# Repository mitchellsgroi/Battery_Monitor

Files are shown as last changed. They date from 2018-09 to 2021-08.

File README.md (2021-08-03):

# Battery_Monitor

Use to monitor Voltage, Current and Amp-Hours of a single 12V sealed lead acid battery.
Also includes temperature monitoring for a fridge freezer.

## About

Despite what 4x4 and caravan accessory companies seem to advertise the state of charge (SoC) of lead acid batteries cannot be determined by measuring voltage alone.

I have created this little Arduino based device to measure the amp-hours that have flowed in and out of the battery to give a more accurate representation of the SoC and hopefully help keep the battery from being overly discharged.

A fairly unique feature of this project is that there is no usage of a shunt to measure current. This is instead achieved by a current sensing coil via hall effect. Therefore installation of the device requires very little modification to existing battery systems.

There is also a demo website included in this repo that gives a basic representation of the monitor in use.

## Notes

- Currently in the process of cleaning everything up after not having being
  touched in over 3 years.

- There are 3 working prototypes in existence that have been running without
  incident now for about 4 or more years including 1 with the current sensor
  mounted in the engine bay.

- I am not going to provide any usage instructions or license at this stage
  until I sort everything out and package it up properly. 

- Contact me if you have any interest in this project and I will help out where I can.

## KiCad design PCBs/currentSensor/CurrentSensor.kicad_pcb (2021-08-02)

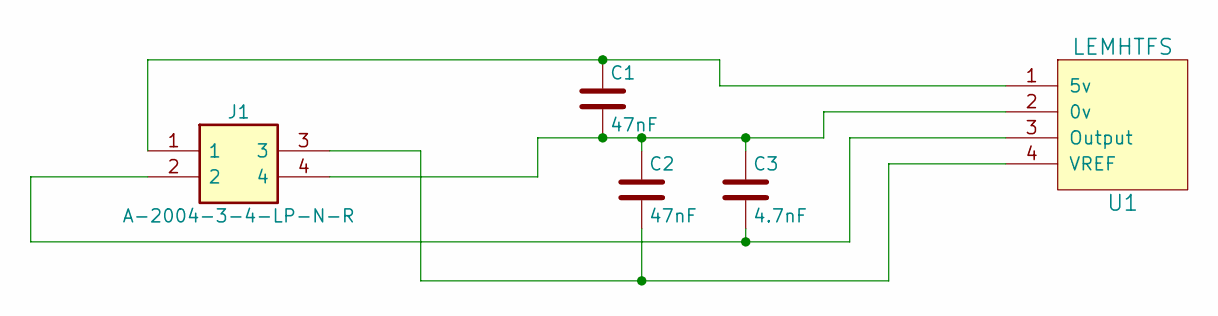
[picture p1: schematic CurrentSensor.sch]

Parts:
C1, C2: 47nF; C_Disc_D4.7mm_W2.5mm_P5.00mm
C3: 4.7nF; C_Disc_D5.0mm_W2.5mm_P2.50mm
J1: A-2004-3-4-LP-N-R; Manufacturer_Part_Number A-2004-3-4-LP-N-R
U1: LEMHTFS; HTFS-Series_LEM-HallEffektCurrentTransducer

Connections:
unnamed: C1.1, J1.1, U1.1 (5v)
unnamed: C1.2, C2.1, C3.1, J1.4, U1.2 (0v)
unnamed: C2.2, J1.3, U1.4 (VREF)
unnamed: C3.2, J1.2, U1.3 (Output)

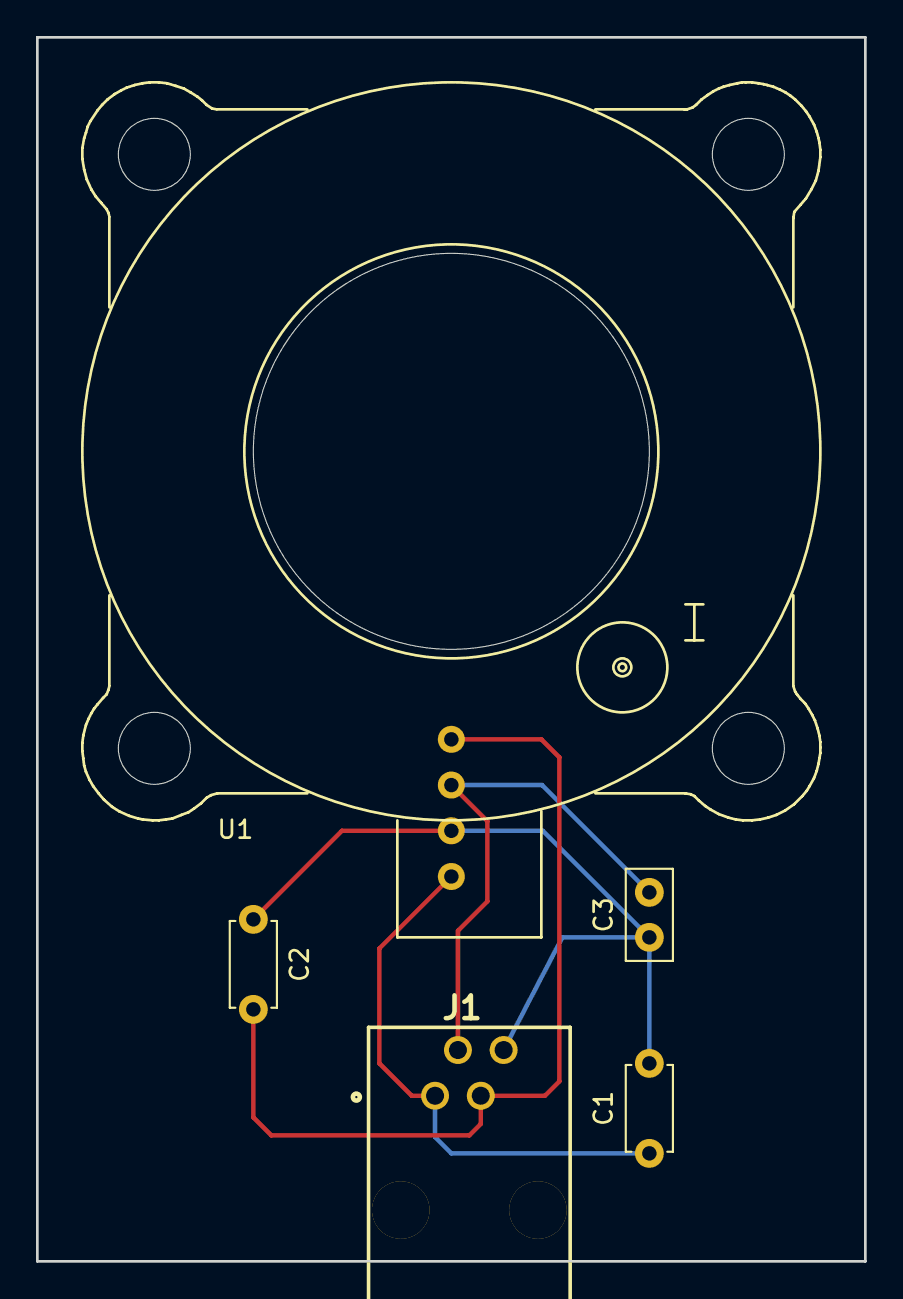
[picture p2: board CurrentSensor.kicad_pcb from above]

Board: 2 copper layers, 46.0 x 68.0 mm, 5 parts (0 on the bottom side), 4 nets.

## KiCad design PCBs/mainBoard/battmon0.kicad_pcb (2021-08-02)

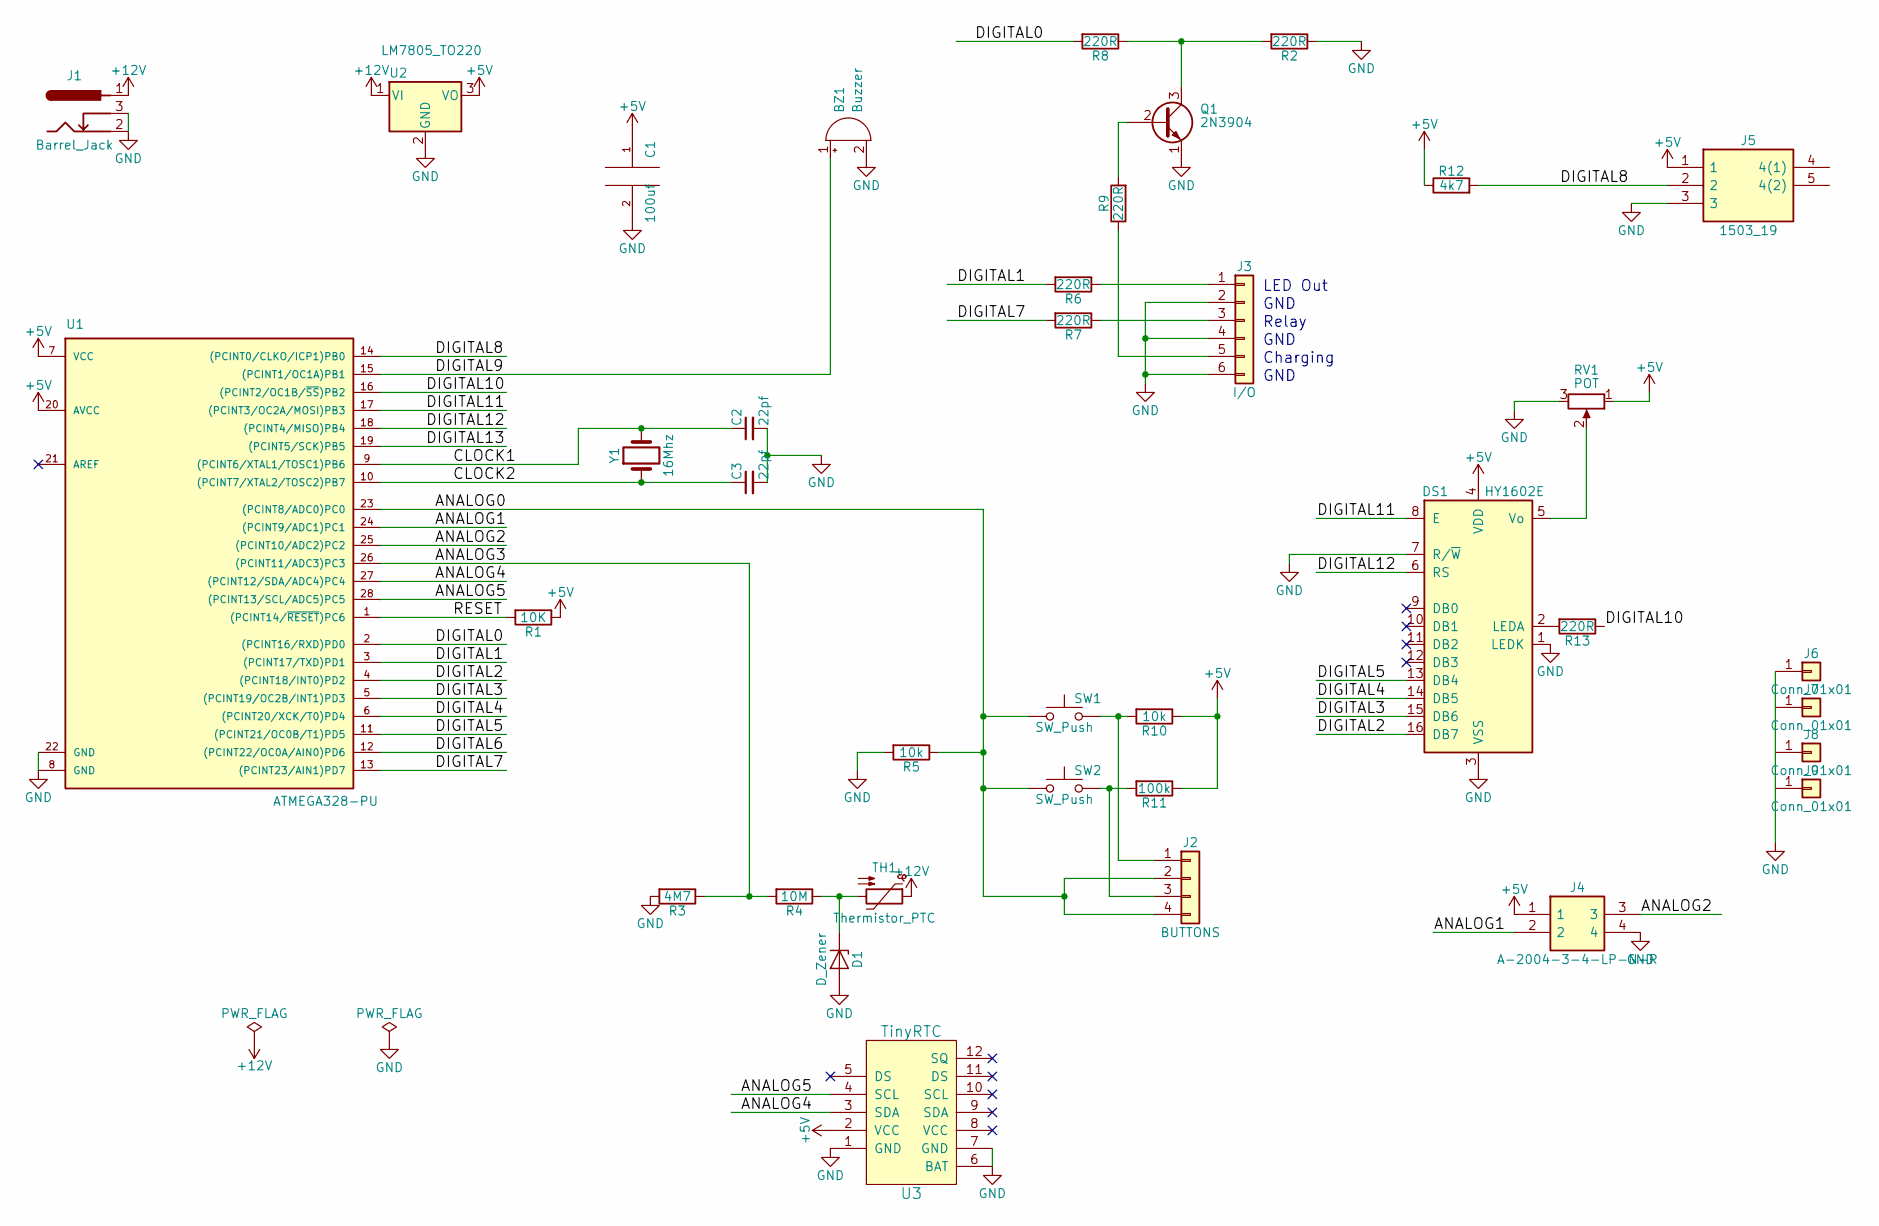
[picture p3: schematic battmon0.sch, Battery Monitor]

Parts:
BZ1: Buzzer; BUZZER
C1: 100uf; CP_Radial_D6.3mm_P2.50mm
C2, C3: 22pf; C_Disc_D3.0mm_W2.0mm_P2.50mm
D1: D_Zener; D_DO-35_SOD27_P7.62mm_Horizontal
DS1: HY1602E; WC1602A
J1: Barrel_Jack; BARREL_JACK
J2: BUTTONS; Molex_KK-6410-04_04x2.54mm_Straight
J3: I/O; Molex_KK-6410-06_06x2.54mm_Straight
J4: A-2004-3-4-LP-N-R; Manufacturer_Part_Number A-2004-3-4-LP-N-R
J5: 1503_19; 1503-19; Manufacturer_Part_Number 1503 19; Farnell Part Number 2677783
J6, J7, J8, J9: Conn_01x01; Mounthole
Q1: 2N3904; TO-92_Molded_Narrow
R1: 10K; R_Axial_DIN0207_L6.3mm_D2.5mm_P10.16mm_Horizontal
R2, R6, R7, R8, R9, R13: 220R; R_Axial_DIN0207_L6.3mm_D2.5mm_P10.16mm_Horizontal
R3: 4M7; R_Axial_DIN0207_L6.3mm_D2.5mm_P10.16mm_Horizontal
R4: 10M; R_Axial_DIN0207_L6.3mm_D2.5mm_P10.16mm_Horizontal
R5, R10: 10k; R_Axial_DIN0207_L6.3mm_D2.5mm_P10.16mm_Horizontal
R11: 100k; R_Axial_DIN0207_L6.3mm_D2.5mm_P10.16mm_Horizontal
R12: 4k7; R_Axial_DIN0207_L6.3mm_D2.5mm_P10.16mm_Horizontal
RV1: POT; Potentiometer_Triwood_RM-065
SW1, SW2: SW_Push; SW_PUSH_6mm_h9.5mm
TH1: Thermistor_PTC; R_Axial_DIN0204_L3.6mm_D1.6mm_P5.08mm_Vertical
U1: ATMEGA328-PU; DIP-28_W7.62mm
U2: LM7805_TO220; TO-220-3_Vertical
U3: TinyRTC
Y1: 16Mhz; Crystal_HC49-U_Vertical

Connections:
+5V: C1.1, DS1.4 (VDD), J4.1, J5.1, R1.1, R10.1, R11.1, R12.1, RV1.1, U1.7 (VCC), U1.20 (AVCC), U2.3 (VO), U3.2 (VCC)
+12V: J1.1, TH1.1, U2.1 (VI)
/ANALOG0: J2.2, J2.4, R5.1, SW1.1, SW2.1, U1.23 ((PCINT8/ADC0)PC0)
/ANALOG1: J4.2, U1.24 ((PCINT9/ADC1)PC1)
/ANALOG2: J4.3, U1.25 ((PCINT10/ADC2)PC2)
/ANALOG3: R3.1, R4.2, U1.26 ((PCINT11/ADC3)PC3)
/ANALOG4: U1.27 ((PCINT12/SDA/ADC4)PC4), U3.3 (SDA)
/ANALOG5: U1.28 ((PCINT13/SCL/ADC5)PC5), U3.4 (SCL)
/CLOCK1: C2.1, U1.9 ((PCINT6/XTAL1/TOSC1)PB6), Y1.2
/CLOCK2: C3.1, U1.10 ((PCINT7/XTAL2/TOSC2)PB7), Y1.1
/DIGITAL0: R8.2, U1.2 ((PCINT16/RXD)PD0)
/DIGITAL1: R6.2, U1.3 ((PCINT17/TXD)PD1)
/DIGITAL2: DS1.16 (DB7), U1.4 ((PCINT18/INT0)PD2)
/DIGITAL3: DS1.15 (DB6), U1.5 ((PCINT19/OC2B/INT1)PD3)
/DIGITAL4: DS1.14 (DB5), U1.6 ((PCINT20/XCK/T0)PD4)
/DIGITAL5: DS1.13 (DB4), U1.11 ((PCINT21/OC0B/T1)PD5)
/DIGITAL6: U1.12 ((PCINT22/OC0A/AIN0)PD6)
/DIGITAL7: R7.2, U1.13 ((PCINT23/AIN1)PD7)
/DIGITAL8: J5.2, R12.2, U1.14 ((PCINT0/CLKO/ICP1)PB0)
/DIGITAL9: BZ1.1 (-), U1.15 ((PCINT1/OC1A)PB1)
/DIGITAL10: R13.1, U1.16 ((PCINT2/OC1B/~SS~)PB2)
/DIGITAL11: DS1.8 (E), U1.17 ((PCINT3/OC2A/MOSI)PB3)
/DIGITAL12: DS1.6 (RS), U1.18 ((PCINT4/MISO)PB4)
/DIGITAL13: U1.19 ((PCINT5/SCK)PB5)
/RESET: R1.2, U1.1 ((PCINT14/~RESET~)PC6)
GND: BZ1.2 (+), C1.2, C2.2, C3.2, D1.2 (A), DS1.1 (LEDK), DS1.3 (VSS), DS1.7 (R/~W), J1.2, J1.3, J3.2, J3.4, J3.6, J4.4, J5.3, J6.1, Q1.1 (E), R2.1, R3.2, R5.2, RV1.3, U1.8 (GND), U1.22 (GND), U2.2 (GND), U3.1 (GND), U3.6 (BAT), U3.7 (GND)
unnamed: D1.1 (K), R4.1, TH1.2
unnamed: DS1.2 (LEDA), R13.2
unnamed: DS1.5 (Vo), RV1.2
unnamed: J2.1, R10.2, SW1.2
unnamed: J2.3, R11.2, SW2.2
unnamed: J3.1, R6.1
unnamed: J3.3, R7.1
unnamed: J3.5, R9.1
unnamed: Q1.2 (B), R9.2
unnamed: Q1.3 (C), R2.2, R8.1

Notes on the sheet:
LED Out
Relay
GND
Charging

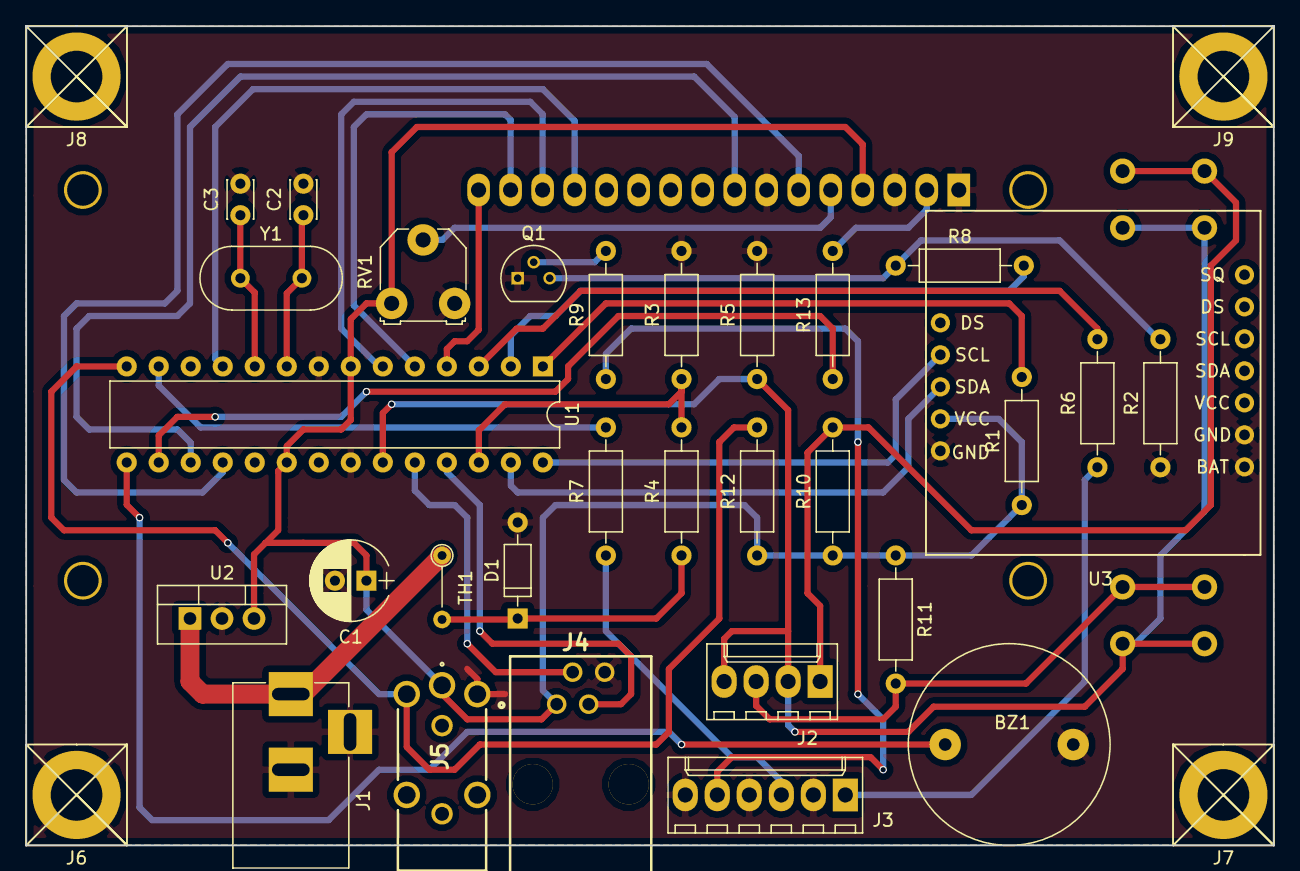
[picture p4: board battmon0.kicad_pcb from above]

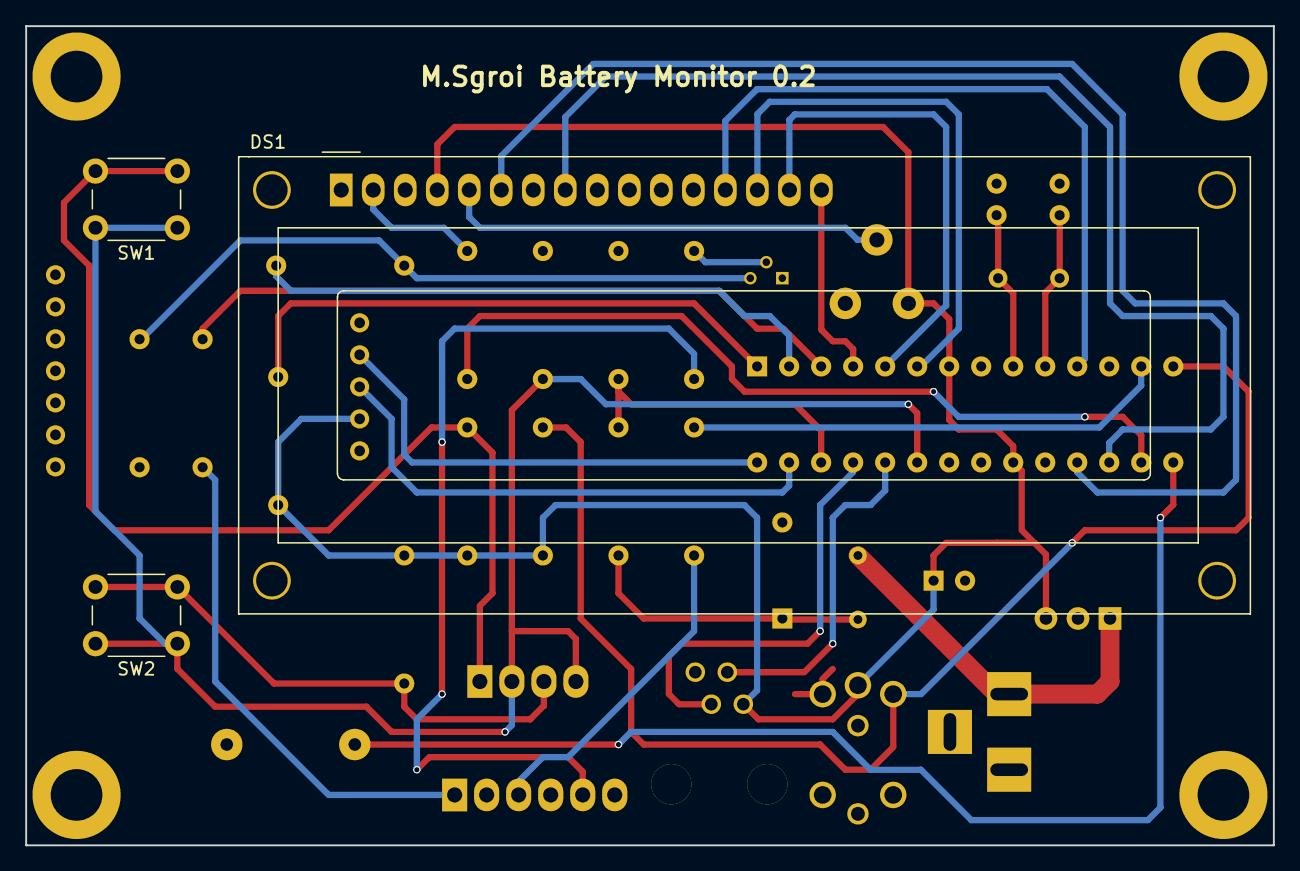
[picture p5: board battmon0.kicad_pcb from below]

Board: 2 copper layers, 99.0 x 65.0 mm, 37 parts (3 on the bottom side), 34 nets.

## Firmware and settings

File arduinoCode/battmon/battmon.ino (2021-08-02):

/*
## TODO
    - DONE-- Change the 15 second interval thing to variable --DONE
    - DONE-- EEPROM Stuff, save the settings, read them and set defaults if no good --DONE
    - Temperature probes, can I have two?
    - DONE-- Fix Enter Setup --DONE
    - DONE-- Make the setup screens actually work --DONE
    - DONE-- Make the alarms actually work --DONE
    - DONE-- Get current readings --DONE
    - DONE-- Stopwatch the AH reading for accuracy --DONE
    - DONE-- truncate the AH rather than round --DONE
    - DONE-- fall back to millis if rtc is broken--DONE
    - DONE-- add rtc status screen in setup --DONE
    - DONE-- Fix display bugs in setup screens -- DONE
    - DONE--Put all the settings into an array of bytes --DONE
    - DONE-- Handle wrong settings --DONE
    - Comment everything
    - DONE-- write float detection --DONE
    - DONE-- Write charge detection current & charge signal --DONE
    - Done-- Write battery capacity tester --Done
    - Done-- Make work on old PCB --DONE
    - Make work on new PCB
    - DONE-- Address amp hour reset bug in capacity tester --DONE
    - DONE-- Change float so only triggered after set time (15min) --DONE
    - DONE-- adjust alarm screens for consistancy. --DONE
    - add amp hour alarm
    - add option to trigger relay on alarm
    - Rearrange code/functions so everything is in an order that makes sense
    - DONE-- Rewrite setup screens to account for extra temp probes --DONE

## BUGS
    - Erratic current readings in test vehicle when running fridge. Switches between positive and negative triggering the charge LED
        - Added smoothing tp each reading before combining them with the LEM current formula. Initial testing shows stable current.
    
    - Float detection will reset amp hours as voltage settles when charger is turned off mid charge.
        - Added a time delay of approx 10min. Monitor must see float conditions for this 10min before resetting amp hours.

    - Backlight doesn't light up while initialising.
        - Initialise pins before startup tests.

    - 2nd Run PCB has different LCD pinout than expected.
        - Use wire instead of terminal strip

    - Amp hours don't reset correctly, flashes 0 then returns to previous number
        - set ampHoourFloat to zero also and retest

    - Float detection needs some fine tuning, rarely detects float
    

*/
// LIBRARIES
#include <Wire.h>
#include "RTClib.h"
#include <LiquidCrystal.h>
#include <EEPROM.h>
#include <OneWire.h>
#include <DallasTemperature.h>

// DEFINITIONS
//#define PROTO
#define PCBONE
//#define PCBTWO

//#define DEBUG
//#define TESTING

#define BUTTON_NONE     0
#define BUTTON_ENTER    1
#define BUTTON_SELECT   2

#define NORMAL 5
#define SETUP 6

#define SETTING_SIZE 30

#define VHAT 0  // Volt High Alarm Tens
#define VHAO 1  // Volt High Alarm Ones 
#define VHAP 2  // Volt High Alarm Point
#define VLAT 3  // Volt Low Alarm Tens
#define VLAO 4
#define VLAP 5

#define THAS 6
#define THAT 7
#define THAO 8
#define THAP 9

#define TLAS 10
#define TLAT 11
#define TLAO 12
#define TLAP 13

#define THAST 14
#define THATT 15
#define THAOT 16
#define THAPT 17

#define TLAST 18
#define TLATT 19
#define TLAOT 20
#define TLAPT 21

#define VA 22
#define TA 23
#define TAT 24

#define WA 25   // Which Alarm

 



// INITIALISE

#ifdef PROTO
    #define ONE_WIRE_BUS 11

    
    
    LiquidCrystal lcd(8,9,4,5,6,7);
    const int chargePin = 2;
    const int backlightPin = 3;
    const int buttonPin = A0;
    const int voltPin = A3;
    const int ledPin = 12;
    const int buzzerPin = 13;
    const int relayPin = 10;

    const int currentVrefPin = A1;
    const int currentVoutPin = A2;


    // VOLTAGE
    float topVolts = 5;
    float kVolts = 1.0;

    // CURRENT
    float kCurrent = 0;

    // BUTTON LEVELS
    int selectVolts = 740;
    int enterVolts = 140;
    
    // FLOAT DETECTION
    float maxVoltage = 0;
    float floatVoltage = 3.0;
    float chargeVoltage = 4.2;
    bool floating = false;
    int floatSeconds = 0;   
    int floatSecondsMax = 600;    

#endif

#ifdef PCBONE // Original PCB
    
    #define ONE_WIRE_BUS 8
    
    LiquidCrystal lcd(12,11,5,4,3,2);

    const int chargePin = 0;
    const int ledPin = 1;
    const int buzzerPin = 9;
    const int backlightPin = 10;
    const int relayPin = 13;
     
    const int buttonPin = A0;
    const int currentVoutPin = A1;
    const int currentVrefPin = A2;
    const int voltPin = A3;

    // VOLTAGE
    float topVolts = 28.5;

    // My car
    float kVolts = 0.97;

    // CURRENT
    float kCurrent = 0.0;

    // BUTTON VOLTAGES
    int selectVolts = 790;
    int enterVolts = 260;

    // FLOAT DETECTION
    float maxVoltage = 0;
    float floatVoltage = 13.2;
    float chargeVoltage = 13.9;
    bool floating = false;
    int floatSeconds = 0;   
    int floatSecondsMax = 600;
     
#endif

#ifdef PCBTWO
    #define ONE_WIRE_BUS 8
    
    LiquidCrystal lcd(12,11,5,4,3,2);

    const int chargePin = 0;
    const int ledPin = 1;
    const int buzzerPin = 9;
    const int backlightPin = 10;
    const int relayPin = 7;
     
    const int buttonPin = A0;
    const int currentVoutPin = A1;
    const int currentVrefPin = A2;
    const int voltPin = A3;

    // VOLTAGE
    float topVolts = 28.5;
    
    //Jayson's Car
    float kVolts = 0.985;
    
    // CURRENT
    float kCurrent = 0.0;

    // BUTTON VOLTAGES
    int selectVolts = 509;
    int enterVolts = 90;

    // FLOAT DETECTION
    float maxVoltage = 0;
    float floatVoltage = 13.4;
    float chargeVoltage = 14.1;
    bool floating = false;
    int floatSeconds = 0;   
    int floatSecondsMax = 600;
    
     
#endif
    

RTC_DS1307 RTC;

OneWire oneWire(ONE_WIRE_BUS);
DallasTemperature sensors(&oneWire);

// VARIABLES

// RTC and Timing
int currentSecond = 0;  // reading the seconds from the RTC
int wasSecond = 0;      // to compare seconds to the last loop
byte secondPassed = false;
byte fifteenSecond = false;
byte fifteenSecondCount = 0;
byte fifteenSecondMax = 15;

byte tempAdvance = false;
byte tempAdvanceCount = 0;
byte tempAdvanceMax = 5;

unsigned long currentMillis = 0;  // millis for each loop for delays
unsigned long refreshMillis = 0;
const int refreshDelay = 1000;
byte refresh = false;

const int numReadings = 50;

// ALARMS
String tempHighString = ("Maximum Temp");
String tempLowString = ("Minimum Temp");
String voltHighString = ("Maximum Volts");
String voltLowString = ("Minimum Volts");
String plus = "+";
String neg = "-";

String no = "No";
String yes = "Yes";

byte settings[SETTING_SIZE];

byte tempAlarm[2];
float tempLowAlarm[2];
float tempHighAlarm[2];
byte tempAlarming[2];

byte voltAlarm = 0;
float voltLowAlarm = 0;
float voltHighAlarm = 0;
byte voltAlarming = false;

int alarmCount = 0;
int alarmMax = 2000;

bool ledOn = false;

// current
int vRefRaw = 0;
int totalVref = 0;
int arrayVref[numReadings];
int iVref = 0;
float vRefAverage = 0;

int vOutRaw = 0;
int totalVout = 0;
int arrayVout[numReadings];
int iVout = 0;
float vOutAverage = 0;
//float vRef = 0;
//float vOut = 0;
float thisCurrent = 0;
float totalCurrent = 0;
float arrayCurrent[numReadings];
int iCurrent = 0;

float current = 0;       // final current to be displayed

// voltage


float voltage = 12.5;     // final voltage to be displayed
int rawVolts = 0;
int arrayVolts[numReadings];
float totalVolts = 0;
int iVolts = 0;
byte voltSetCount = 0;

// CHARGING

int chargeHigh = LOW;
bool isCharging = false;


// Battery Testing
byte batteryTest = 0;
byte startTesting = 0;
byte isTesting = 0;
byte doneTesting = true;
float testResult = 0;
bool relayOn = false;


// amp hours
int ampHours = 0;     // total amp hours
float ampHourFloat = 0;
byte ampHourReset = 0;

// temperature
float tempReadings[2];
byte tempIndex = 0;
int numTempSensors = 0;


// buttons
unsigned long buttonMillis = 0;
const int buttonDelay = 50;
const int buttonHyst = 10; // How many volts above or below the ones set above
int rawButton = 0;
byte whichButton = 0;
byte buttonAction = false;
byte buttonPressed = 0;
byte buttonWas = 0;

int screenReturn = 0;
int screenMax = 3000;

byte *selectAddress;
byte *enterAddress;

byte selectModulo = 0;
byte enterModulo = 0;

// CURSOR AND ALARM FLASHING
byte flashState = true;
unsigned long lastFlashMillis = 0;
const int flashDelay = 250;


// settings
byte selectCount = 0;
byte backlightLevel = 0;
byte setupCount = 0;
byte tempSetCount = 0;
byte numScreens = 5;

byte enterSetup = false;
byte exitSetup = 0;

// AH SYMBOL
byte ahSymbol[8] = {
  B01000,
  B10100,
  B11100,
  B10100,
  B00000,
  B00101,
  B00111,
  B00101,
};

String tempAlarmHeader = "Temp Range";


void setup() {
    // NEW BEGININGS
     Wire.begin();
    lcd.createChar(2, ahSymbol);
    lcd.begin(16,2);
    
   
    RTC.begin();
    // sensors.begin();  // Moved to function

    // PIN THE TAIL ON THE DONKY
    pinMode(backlightPin, OUTPUT);
    pinMode(ledPin, OUTPUT);
    pinMode(buzzerPin, OUTPUT);
    pinMode(relayPin, OUTPUT);   
    pinMode(buttonPin, INPUT);
    #ifdef PCBONE
        pinMode(buttonPin, INPUT_PULLUP);
    #endif
    pinMode(voltPin, INPUT);
    pinMode(currentVrefPin, INPUT);
    pinMode(currentVoutPin, INPUT);
    

    digitalWrite(backlightPin, HIGH);
    digitalWrite(ledPin, LOW);
    digitalWrite(buzzerPin, LOW);
    digitalWrite(relayPin, HIGH);

    if (!RTC.isrunning()){
        lcd.clear();
        lcd.print(F("RTC Resetting"));
        delay(200);
        RTC.adjust(DateTime(__DATE__, __TIME__)); 
    }

    if (!RTC.isrunning()){
        lcd.clear();
        lcd.print(F("RTC ERROR"));
        delay(2000);
    }

    // PRINT TO LCD AS FAUX SPLASH SCREEN
    lcd.clear();
    lcd.print(F("  The Battery   "));
    lcd.setCursor(0, 1);
    lcd.print(F("    Monitor     "));
    delay(300);



    // CLEAR AVERAGING ARRAYS
    for (int i = 0; i < numReadings; i++) {
        arrayVolts[i] = 0;
        arrayCurrent[i] = 0;
        arrayVref[i] = 0;
        arrayVout[i] = 0;
    }

//    // Read the temps sensor on startup
//    sensors.requestTemperatures();
//    // ping the sensor(s) for the temp reading
//    temp = sensors.getTempCByIndex(0);

    

    // read persistant values from the EEPROM
    settingsRead();

    // set up the alarm values
    convertAlarms();

    setupTempSensors();
    
    lcd.clear();
    
}

void setupTempSensors() {

    // check the number of temp sensors connected
    // make a correctly sized array to store the values
    // read all the temps and save them to the array (for loop)
    // either return the array or make a global variable.
    
    sensors.begin();
    delay(10);
    numTempSensors = sensors.getDeviceCount();

    if (numTempSensors > 2) {
        numTempSensors = 2;
    }

    lcd.clear();
    lcd.print(numTempSensors);
    lcd.print(F(" Temp Probe(s)"));
    delay(500);

    sensors.requestTemperatures();

    for (int i = 0; i < numTempSensors; i++) {
        tempReadings[i] = sensors.getTempCByIndex(i);
    }
}

void loop() {
    // Do all the millis related functions
    checkMillis();
    // Do all the second related functions
    checkSecond();
    // Check the voltage of the battery
    batteryVoltage();
    // Check the current in or out of the battery
    batteryCurrent();
    // Check if the battery is floating
    floatDetect();
    // Check if the battery is charging
    charging();
    // Check the temperature
    temperature();     
    // Count the Amp Hours
    countAmpHours();
    // Trigger any alarms
    triggerTempAlarm(0, TA);
    if (numTempSensors > 1) {
        triggerTempAlarm(1, TAT);
    }
    else {
        tempAlarming[1] = false;
    }
    triggerVoltAlarm();
    // Set off buzzer or LED
    soundAlarm();
    // Check if a button has been presseds
    buttons();
    // Print info the the LCD
    displayScreen();
    // Return to home screen if no activity
    returnHome();   
}

byte checkButton(){

    rawButton = analogRead(buttonPin);
    
    if (rawButton > (selectVolts - buttonHyst) && rawButton < (selectVolts + buttonHyst)) {
        buttonPressed = BUTTON_SELECT;
    }
    else if (rawButton > (enterVolts - buttonHyst) && rawButton < (enterVolts + buttonHyst)) {
        buttonPressed = BUTTON_ENTER;
    }
    else {
        buttonPressed = BUTTON_NONE;
    }

    if (buttonWas == BUTTON_NONE && buttonPressed != BUTTON_NONE) {
        buttonAction = true;
    }

    buttonWas = buttonPressed;

    return buttonPressed;
}

void setBack() {
    // Sets the level of the LCD backlight
    switch (backlightLevel) {
        case 0:
            digitalWrite(backlightPin, HIGH);
        break;
        case 1:
            analogWrite(backlightPin, 127);
        break;
        case 2:
            digitalWrite(backlightPin, LOW);
        break;
    }
}
void checkMillis() {
    // capture millis at the start of the loop
    currentMillis = millis();
    
    if ((currentMillis - refreshMillis) > refreshDelay) {
        refresh = true;
        refreshMillis = currentMillis;
    }

    else {
        refresh = false;
    }
    if ((currentMillis - lastFlashMillis) > flashDelay) {
        flashState = !flashState;
        lastFlashMillis = currentMillis;
    }
}

void checkSecond() {
    if (RTC.isrunning()){

        DateTime now = RTC.now();
        currentSecond = now.second();
    
        if (currentSecond != wasSecond) {
            secondPassed = true;
        }
        else {
            secondPassed = false;
        }
    
        // change the magic 15 here to a variable that can be changed
        if (((currentSecond % fifteenSecondMax) == 0) && secondPassed) {
            fifteenSecond = true;
        }
        else {
            fifteenSecond = false;
        }

        if (((currentSecond % tempAdvanceMax) == 0) && secondPassed) {
            tempAdvance = true;
        }
        else {
            tempAdvance = false;
        }
        
        wasSecond = currentSecond;
    }
    else {
         if (refresh) {
            secondPassed = true;
            if (fifteenSecondCount >= fifteenSecondMax) {
                fifteenSecond = true;
                fifteenSecondCount = 0;
            }
            fifteenSecondCount++;

            if (tempAdvanceCount >= tempAdvanceMax) {
                tempAdvance = true;
                tempAdvanceCount = 0;
            }
            tempAdvanceCount++;
         }
         else {
            secondPassed = false;
            fifteenSecond = false;
            tempAdvance = false;
         }
    }
}

void batteryVoltage() {
    // Take the analog input
    rawVolts = analogRead(voltPin);
    // Take the old value from the total
    totalVolts -= arrayVolts[iVolts];
    // Put the new value in the array
    arrayVolts[iVolts] = rawVolts;
    // Add the new value to the array
    totalVolts += arrayVolts[iVolts];
    // increment the array index
    iVolts++;
    // reset the index at the end of the array
    if (iVolts >= numReadings) {
        iVolts = 0;
    }
    delay[1];

    // calculate average voltage
    voltage = ((totalVolts / numReadings) * (topVolts / 1023.0)) * kVolts;    
}



void batteryCurrent() {
    
    vRefRaw = analogRead(currentVrefPin);
    vOutRaw = analogRead(currentVoutPin);

    // take the old value from the total
    totalVref -= arrayVref[iVref];
    // Insert the new value
    arrayVref[iVref] = vRefRaw;
    // Add this new value to the total
    totalVref += arrayVref[iVref];
    // Go to next index
    iVref++;
    // Reset index if at the end of array
    if (iVref >= numReadings) {
        iVref = 0;
    }
    delay[1];

    vRefAverage = totalVref / numReadings;


        // take the old value from the total
    totalVout -= arrayVout[iVout];
    // Insert the new value
    arrayVout[iVout] = vOutRaw;
    // Add this new value to the total
    totalVout += arrayVout[iVout];
    // Go to next index
    iVout++;
    // Reset index if at the end of array
    if (iVout >= numReadings) {
        iVout = 0;
    }
    delay[1];

    vOutAverage = totalVout / numReadings;
    

    thisCurrent = 160 * (vOutAverage - vRefAverage);

    // take the old value from the total
    totalCurrent -= arrayCurrent[iCurrent];
    // Insert the new value
    arrayCurrent[iCurrent] = thisCurrent;
    // Add this new value to the total
    totalCurrent += arrayCurrent[iCurrent];
    // Go to next index
    iCurrent++;
    // Reset index if at the end of array
    if (iCurrent >= numReadings) {
        iCurrent = 0;
    }
    delay[1];

    // calculate the average
    current = ((totalCurrent / numReadings) * (5.0 / 1023.0)) + kCurrent;

    if (current < 0.4 && current > -0.4) {
        current = 0;
    }
    
    
}

void countAmpHours() {
    if (secondPassed) {
        ampHourFloat += current / 3600;

        if (ampHourFloat < 0) {
            ampHourFloat = 0;
        }

    ampHours = ampHourFloat;
    }
}

void temperature() {
    // TEMPERATURE
    if (fifteenSecond && !selectCount && !batteryTest) {
        // request readings from all temp sensors
        sensors.requestTemperatures();
        // save the readings to the array
        for (int i = 0; i < numTempSensors; i++) {
            tempReadings[i] = sensors.getTempCByIndex(i);
        }
    }    
}

void triggerTempAlarm(byte i, byte settingIndex) {
    switch(settings[settingIndex]) {
        case 0:
            tempAlarming[i] = false;
        break;
        case 1:
            if (tempReadings[i] >= tempHighAlarm[i] || tempReadings[i] <= tempLowAlarm[i]) {
                tempAlarming[i] = true;
                alarmCount = alarmMax;
            }
            else {
                tempAlarming[i] = false;
            }
        break;
        case 2:
            if (tempReadings[i] >= tempHighAlarm[i]) {
                tempAlarming[i] = true;
                alarmCount = alarmMax;
            }
            else {
                tempAlarming[i] = false;
            }
        break;    
        case 3:
            if (tempReadings[i] <= tempLowAlarm[i]) {
                tempAlarming[i] = true;
                alarmCount = alarmMax;
            }
            else {
                tempAlarming[i] = false;
            }
        break;
    }


}

void triggerVoltAlarm() {
    switch(settings[VA]) {
        case 0:
            voltAlarming = false;
        break;
        case 1:
            if (voltage >= voltHighAlarm || voltage <= voltLowAlarm) {
                voltAlarming = true;
                alarmCount = alarmMax;
            }
            else {
                voltAlarming = false;
            }
        break;
        case 2:
            if (voltage >= voltHighAlarm) {
                voltAlarming = true;
                alarmCount = alarmMax;    
            }
            else {
                voltAlarming = false;
            }
        break;
        case 3:
            if (voltage <= voltLowAlarm) {
                voltAlarming = true;
                alarmCount = alarmMax;
            }
            else {
                voltAlarming = false;
            }
        break;
    }
}


void soundAlarm() {
    if (voltAlarming || tempAlarming[0] || tempAlarming[1] || alarmCount) {
        switch (settings[WA]) {
            case 0:
             setLed(0);
             digitalWrite(buzzerPin, LOW);
            break;
            case 1:
                flashLed();
                flashBuzzer();
            break;
            case 2:
                flashLed();
                digitalWrite(buzzerPin, LOW);
            break;
            case 3:
                flashBuzzer();
                setLed(0);
            break;
        }
    }
    else {
        if (isCharging) {
            setLed(1);
        }
        else {
            setLed(0);
        }
        digitalWrite(buzzerPin, LOW);
    }

    if ((!voltAlarming || !tempAlarming[0] || !tempAlarming[1]) && alarmCount > 0) {
        alarmCount-- ;
    }
    
}

void buttons() {
    // Check the button press wasn't a bounce
    if ((currentMillis - buttonMillis) > buttonDelay) {
        // check which button it was
        whichButton = checkButton();
        // reset the debounce timer
        buttonMillis = currentMillis;
        // check if the button pressed should trigger an action
        if (buttonAction == true) {
            // reset the activity timer
            screenReturn = 0;
            // do the action that is required
            buttonIncrement();
            // reset the action trigger
            buttonAction = false;
        }
    }
}

void returnHome() {
    // If not on the home screen    
    if (selectCount != 0) {
        // Increment the count
        screenReturn++;
        // If count has reached the max value
        if (screenReturn >= screenMax) {
            // Clear the LCD
            lcd.clear();
            // Return to the home screen
            selectCount = 0;
            // Reset the count
            screenReturn = 0;
        }
    }
}
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

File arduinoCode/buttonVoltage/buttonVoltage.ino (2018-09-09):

/*
  LiquidCrystal Library - display() and noDisplay()

 Demonstrates the use a 16x2 LCD display.  The LiquidCrystal
 library works with all LCD displays that are compatible with the
 Hitachi HD44780 driver. There are many of them out there, and you
 can usually tell them by the 16-pin interface.

 This sketch prints "Hello World!" to the LCD and uses the
 display() and noDisplay() functions to turn on and off
 the display.

 The circuit:
 * LCD RS pin to digital pin 12
 * LCD Enable pin to digital pin 11
 * LCD D4 pin to digital pin 5
 * LCD D5 pin to digital pin 4
 * LCD D6 pin to digital pin 3
 * LCD D7 pin to digital pin 2
 * LCD R/W pin to ground
 * 10K resistor:
 * ends to +5V and ground
 * wiper to LCD VO pin (pin 3)

 Library originally added 18 Apr 2008
 by David A. Mellis
 library modified 5 Jul 2009
 by Limor Fried (http://www.ladyada.net)
 example added 9 Jul 2009
 by Tom Igoe
 modified 22 Nov 2010
 by Tom Igoe
 modified 7 Nov 2016
 by Arturo Guadalupi

 This example code is in the public domain.

 http://www.arduino.cc/en/Tutorial/LiquidCrystalDisplay

*/

// include the library code:
#include <LiquidCrystal.h>

// initialize the library by associating any needed LCD interface pin
// with the arduino pin number it is connected to
const int rs = 12, en = 11, d4 = 5, d5 = 4, d6 = 3, d7 = 2;
LiquidCrystal lcd(rs, en, d4, d5, d6, d7);

int backlightPin = 10;
int buttonPin = A0;

int voltage = 0;

void setup() {
  // set up the LCD's number of columns and rows:
  pinMode(backlightPin, OUTPUT);
  digitalWrite(backlightPin, HIGH);

  pinMode(buttonPin, INPUT);
  
  lcd.begin(16, 2);
  
  // Print a message to the LCD.
  
}

void loop() {
    lcd.clear();
    lcd.setCursor(0, 0);
    lcd.print("Button Voltage");
    voltage = analogRead(buttonPin);
    lcd.setCursor(0, 1);
    lcd.print(voltage);
}

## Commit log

2018-03-24 Further setup of repo
    Added TODOs and BUGS to readme.
    Fixed folder structure to suit arduino ide
    [battmon.ino]
2018-05-13 add RTC test
    Added a sketch for testing the RTC.
    Adds 1 every second and prints the number to the LCD. Use stopwatch to compare accuracy.
2018-05-14 Make buttons work
    Delete all old code and start from scratch. Make the buttons count when pressed
2018-05-14 add screen placeholders
    Adjusted buttons, added screen placeholders, implemented RTC second counting
2018-05-15 add volt reading and smoothing, add amphour symbol
2018-05-16 Set up alarm screens
    Made the alarm screens work. added amp hour reset functionality. Added return to home screen automatically
    [battmon.ino]
2018-05-17 Fix access to setup menu
    Can now enter and exit the settings menu
    [battmon.ino]
2018-05-19 Develop setting screens
    Addes flash function to create faux cursor. Solved some issues with the RTC.
    [battmon.ino]
2018-05-19 Nut out pointer stuff for buttons
2018-05-19 develop settings screens
    Make the temperature alarm setting screens work
2018-05-21 Volt and Temp alarms
    Made the alarms trigger at the set values
2018-05-23 Make thermometer and current reading work
2018-05-23 Capacity Tester
2018-05-26 work towards full PCB compatibility
2018-05-27 Revert "work towards full PCB compatibility"
    This reverts commit 5e2b64584d89cdf549f13917bd7779cb2c238dab.
    [battmon.ino]
2018-05-27 Revert "scrap softwire"
    This reverts commit 2c057f420a9aba92f44af993ab14fa2e42b0b61f.
    [battmon.ino, buttonVoltage.ino]
2018-05-28 add timer to float detect
2018-05-31 Stabilise Current Readings
    Current readings were erratic during testing. Added a layer of smoothing to each analog pin before combining and smoothing again.
    [battmon.ino]
2018-05-31 Comment and fix backlight bug
    [battmon.ino]
2018-06-01 Adjust volt alarm screen
2018-06-01 Add multi temp probe testing
2018-06-13 work through support for mulitple temp probes
2018-06-14 Make fully functional with two temp probes
    Ready for field testing
2018-06-16 Refactor volt limit setup screen
    New function similar to the temperature setup
2018-09-09 Fix settings test to work with one temp probe
    [battmon.ino, buttonVoltage.ino]
2021-08-02 Add Kicad PCB Projects
    [CurrentSensor-B.Cu.gbr, CurrentSensor-B.Mask.gbr, CurrentSensor-B.SilkS.gbr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]
